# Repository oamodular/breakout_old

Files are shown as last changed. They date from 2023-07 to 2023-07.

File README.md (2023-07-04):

# Breakout

A conduit from the USB on the rear of a module to the face of your modular setup. Breakout has a USB-A port on the rear that is routed to either the USB-A or USB-C port on the front. The rear also has three-pin connector for I2C that is exposed with a mini-TRS socket on the front.

Between you me and the sea, we designed this to accompany several upcoming firmware for [Uncertainty](https://oamodular.org/products/uncertainty) but realized this could be useful for lots of people. Modules like Instruo Lubadh and o_C (most versions) have USB on them that can be brought to the surface of your system.

Breakout is USB 2. USB 3 speeds are not supported.

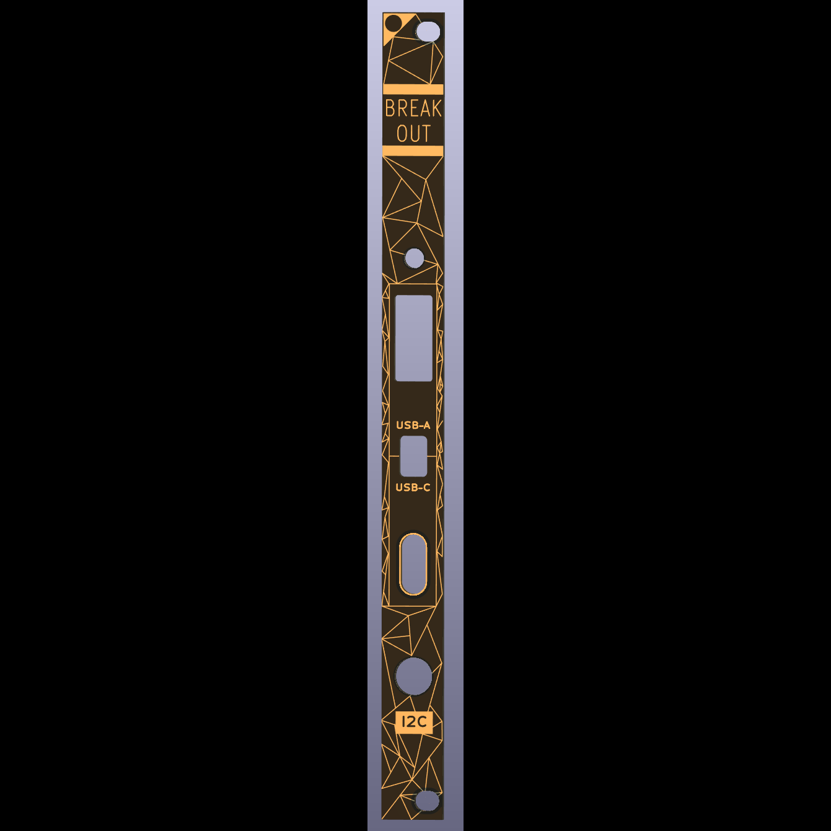
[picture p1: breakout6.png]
faceplate of breakout. has a usb-c and a usb-a hole. has a path cable socket sized hole beneath those


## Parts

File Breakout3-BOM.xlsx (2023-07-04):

Item # | Designator | Quantity | Manufacturer | Mfg Part # | Descripton / Value | Package / Footprint | Type | Notes
1 | J1 | 1 | Alpha/Thonk | PJ398SM-12 | Thonkiconn 3.5mm socket | THT | DNS | DO NOT INCLUDE
2 | SW1 | 1 | Alps Alpine | SSSF040800 | Slide Switch 4-pole ON-ON | THT | DNS | DO NOT INCLUDE
3 | USB3 | 1 | GCT | USB4115-03-C | USB Connectors USB C Rec 3u" vert 24p SMT & TH stakes pegs T+R+C H = 9.25 | SMD | SMD | Assemble this part only
4 | USB1, USB2 | 2 | Molex | 105057-0001 | USB Connectors FY09 VERTICAL USB A TYPE | THT | DNS | DO NOT INCLUDE
5 | H1 | 1 |  |  | 1x3 Pin Connector P2.54 | THT | DNS | DO NOT INCLUDE
6 | H2 | 1 |  |  | M3 standoff |  | DNS | DO NOT INCLUDE
7 | H3 | 1 |  |  | M3 screw |  | DNS | DO NOT INCLUDE
8 | H4 | 1 |  |  | M3 nut |  | DNS | DO NOT INCLUDE

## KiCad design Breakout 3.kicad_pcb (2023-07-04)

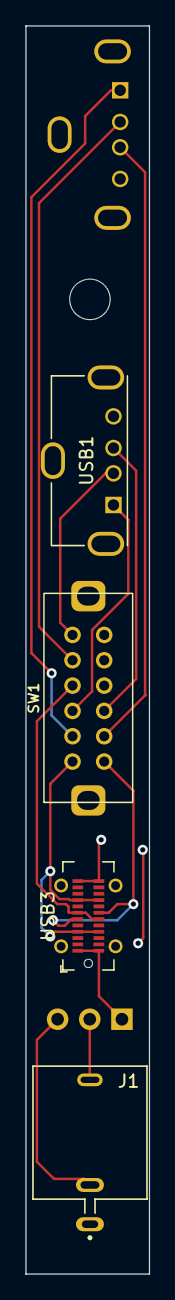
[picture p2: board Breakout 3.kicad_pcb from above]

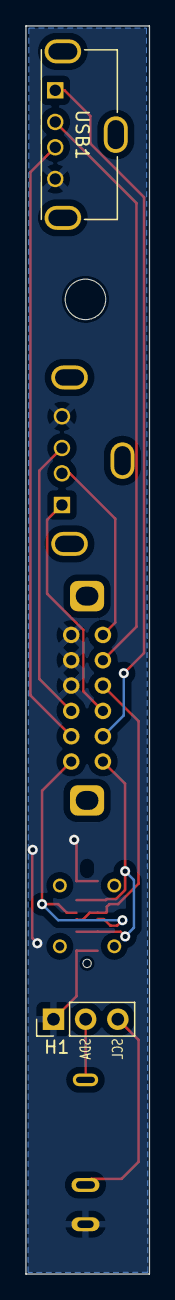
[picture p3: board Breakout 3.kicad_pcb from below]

Board: 2 copper layers, 9.8 x 98.6 mm, 6 parts (2 on the bottom side), 10 nets.

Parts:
H1: PinHeader_1x03_P2.54mm_Vertical
J1: THONK_PJ398SM-12; Socket-3.5mm THT-Thonkiconn PJ398SM-12
SW1: SSSF040800; Switch-4PDT Vertical THT-SSSF040800
USB1, USB1#2: USB_A_Molex_105057_Vertical
USB3: USB_C_Receptacle_GCT_USB4115-03-C

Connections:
D+: SW1.8, USB1#2.3
D+A: SW1.9, USB1.3
D+C: SW1.7, USB3.A6, USB3.B6
D-: SW1.5, USB1#2.2
D-A: SW1.6, USB1.2
D-C: SW1.4, USB3.A7, USB3.B7
Ground: H1.1, J1.1, SW1.10, SW1.11, SW1.12, USB1.4, USB1#2.4, USB3.A1, USB3.A12, USB3.B1, USB3.B12
Vcc: SW1.2, USB1#2.1
Vcc-A: SW1.3, USB1.1
Vcc-C: SW1.1, USB3.A4, USB3.A9, USB3.B4, USB3.B9
